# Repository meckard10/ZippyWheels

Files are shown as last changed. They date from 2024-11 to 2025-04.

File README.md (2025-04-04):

# ZippyWheels
Clemson Senior Design II Project

Melody Eckard, Xander Hagler, Nitya Harikumar, Karlee Kesler, Covington Loftus

## Overview

Remote-controlled roller skates project.

## Folders

1. /Pi PICOW C Code
	- contains C/C++ code for a Raspberry Pi Pico W

2. /Remote Design
	- contains PCB design files and 3D design for remote body
	- Autodesk EAGLE CAD, KiCAD, and SOLIDWORKS were used for these files

3. /Skate Design
	- contains 3D design files for skate body
	- Autodesk Inventor was used for these files

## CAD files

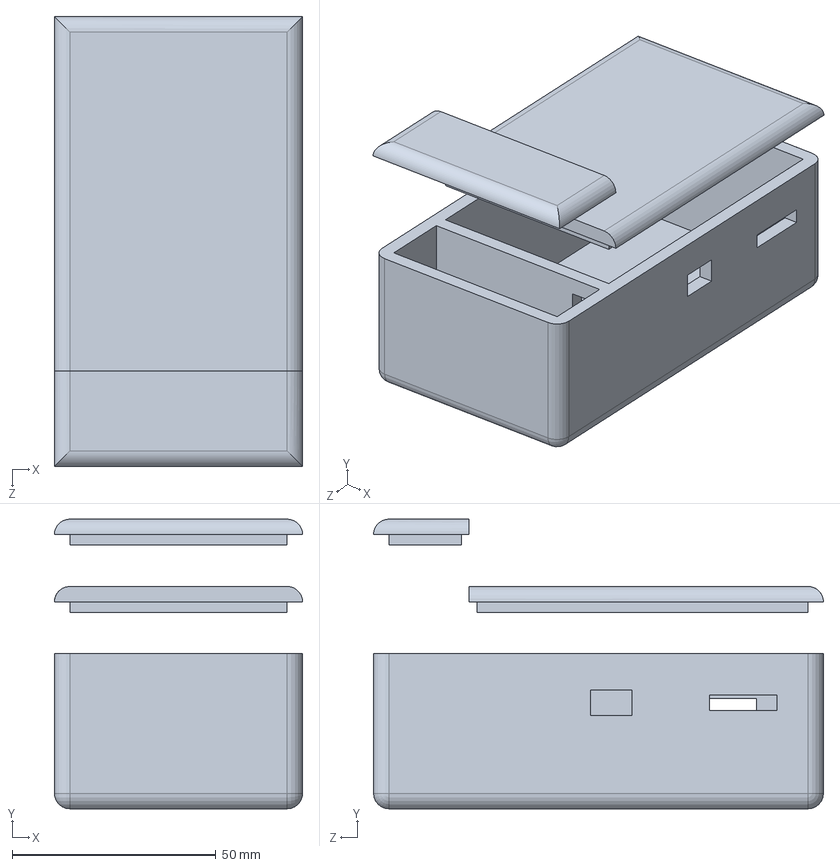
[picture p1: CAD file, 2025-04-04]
Remote_Design/remote.SLDPRT
61.0 x 71.1 x 110.5 mm

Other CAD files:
Remote_Design/remote.STL
Skate_Design/SkateBodyV2.ipt
Skate_Design/SkateLidV1.ipt

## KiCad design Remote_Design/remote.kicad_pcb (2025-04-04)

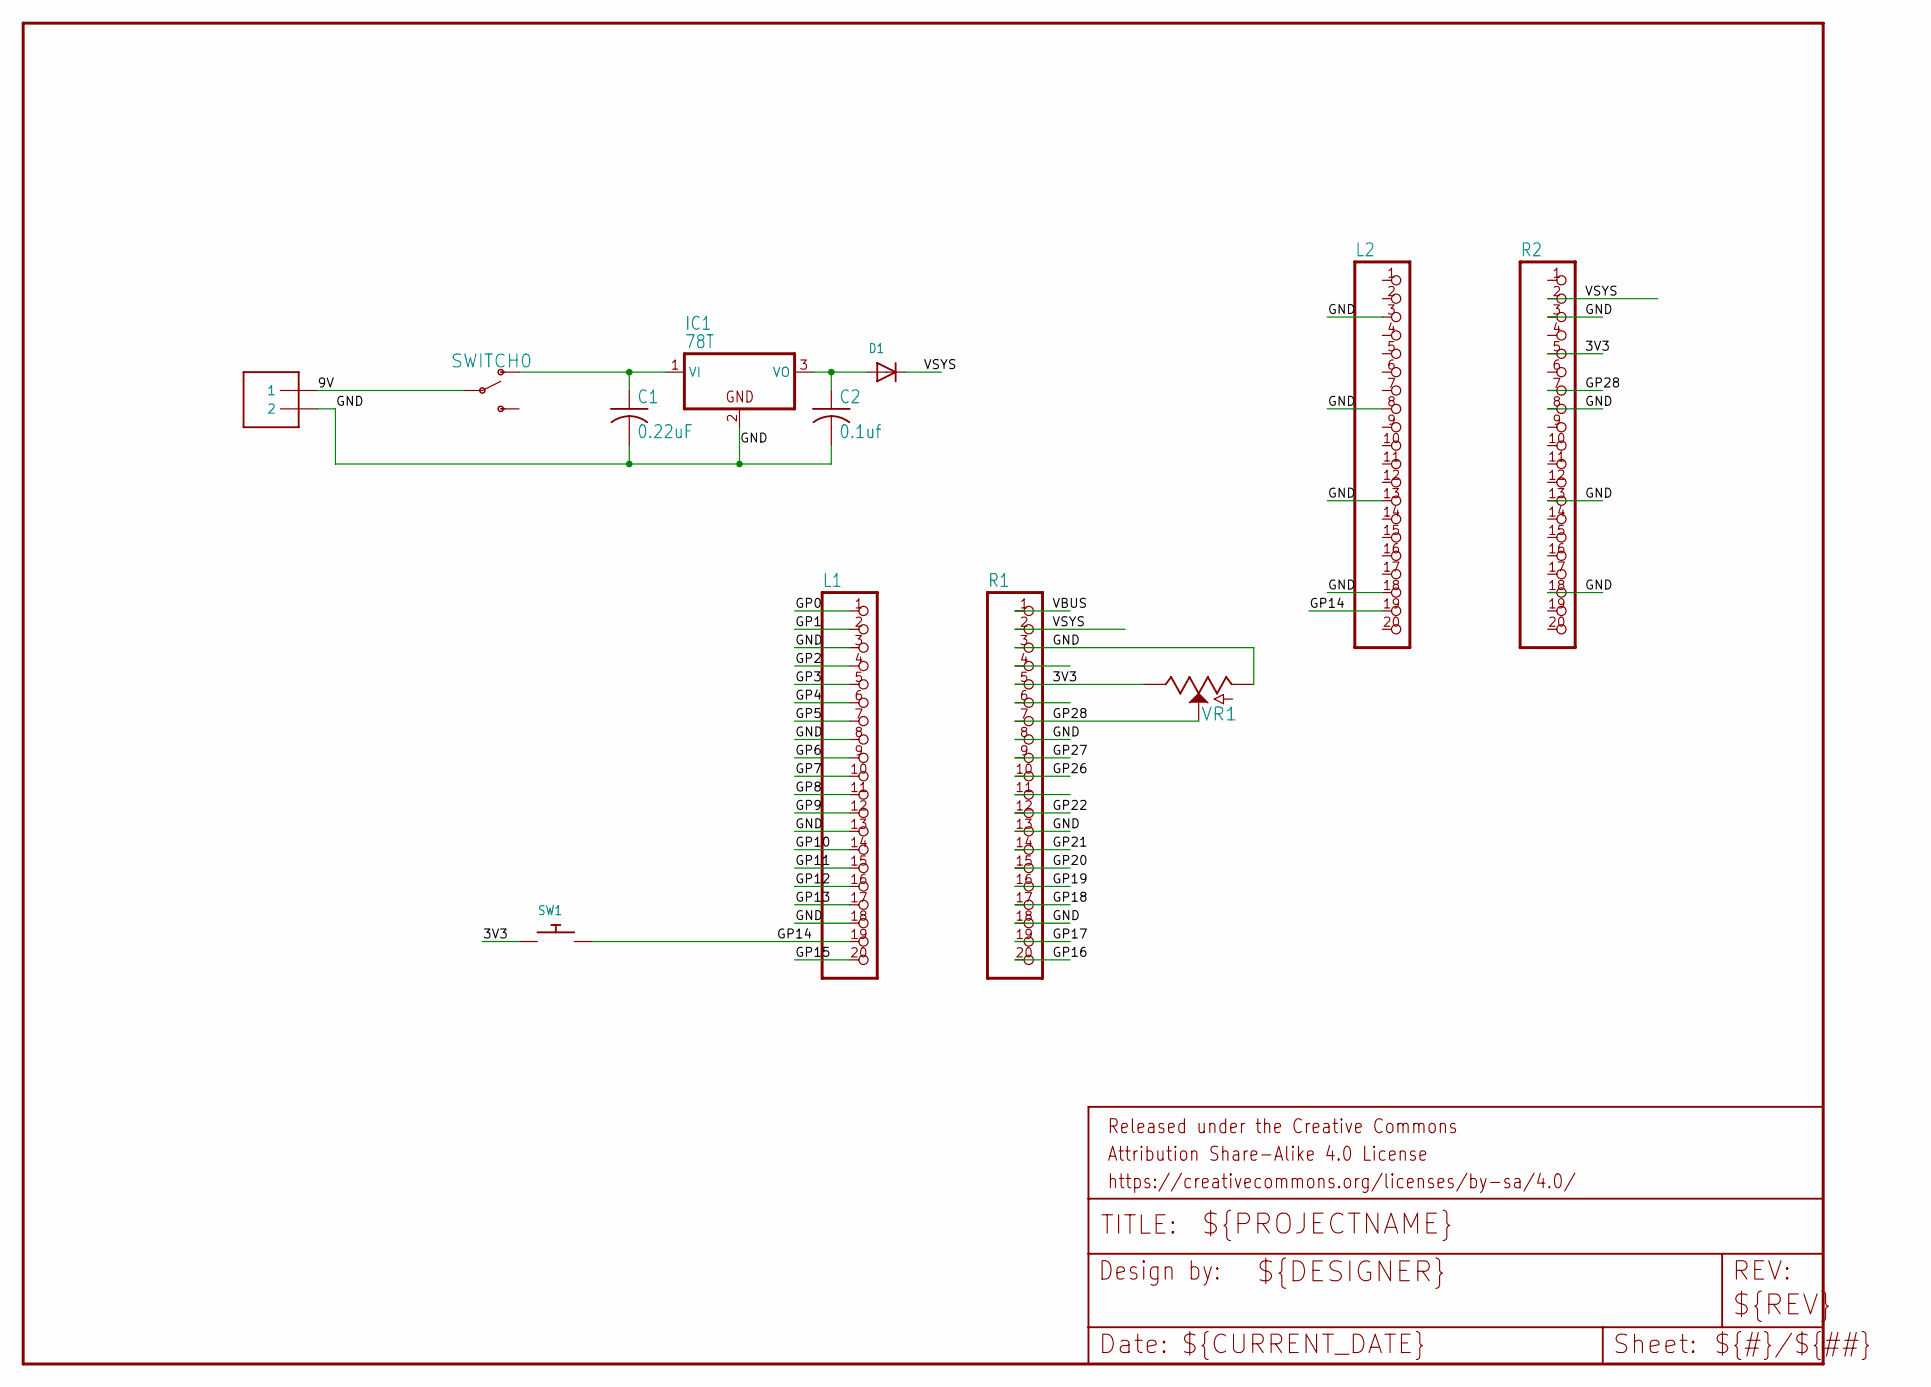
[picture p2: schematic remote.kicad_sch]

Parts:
C1: 0.22uF; C050-025X075
C2: 0.1uf; C050-025X075
D1: DIODEDO-1N4148; DO-1N4148
FRAME1: FRAME-LETTER; CREATIVE_COMMONS
IC1: 78T; TO220H
L1, L2: PINHD-1X20; 1X20
R1, R2: PINHD-1X20; 1X20
SW1: SWITCH_PUSHBUTTONEVQ-PE; TACT_PANA-EVQ
SWITCH0: SWITCH-SPDT-PTH-11.6X4.0MM-LOCK; SWITCH_SPDT_PTH_11.6X4.0MM_LOCK
UNK9VBAT0: 1X2-3.5MM
VR1: 10k; POT-PTH-ALPS

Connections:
3V3: R1.5, R2.5, SW1.P$1, VR1.P$1 (E)
9V: SWITCH0.2, UNK9VBAT0.1
GND: C1.2, C2.2, IC1.2 (GND), L1.3, L1.8, L1.13, L1.18, L2.3, L2.8, L2.13, L2.18, R1.3, R1.8, R1.13, R1.18, R2.3, R2.8, R2.13, R2.18, UNK9VBAT0.2, VR1.P$3 (A)
GP0: L1.1
GP1: L1.2
GP2: L1.4
GP3: L1.5
GP4: L1.6
GP5: L1.7
GP6: L1.9
GP7: L1.10
GP8: L1.11
GP9: L1.12
GP10: L1.14
GP11: L1.15
GP12: L1.16
GP13: L1.17
GP14: L1.19, L2.19, SW1.P$2
GP15: L1.20
GP16: R1.20
GP17: R1.19
GP18: R1.17
GP19: R1.16
GP20: R1.15
GP21: R1.14
GP22: R1.12
GP26: R1.10
GP27: R1.9
GP28: R1.7, R2.7, VR1.P$2 (S)
unnamed: C2.1, D1.A, IC1.3 (VO)
unnamed: C1.1, IC1.1 (VI), SWITCH0.1 (O)
VBUS: R1.1
VSYS: D1.C, R1.2, R2.2

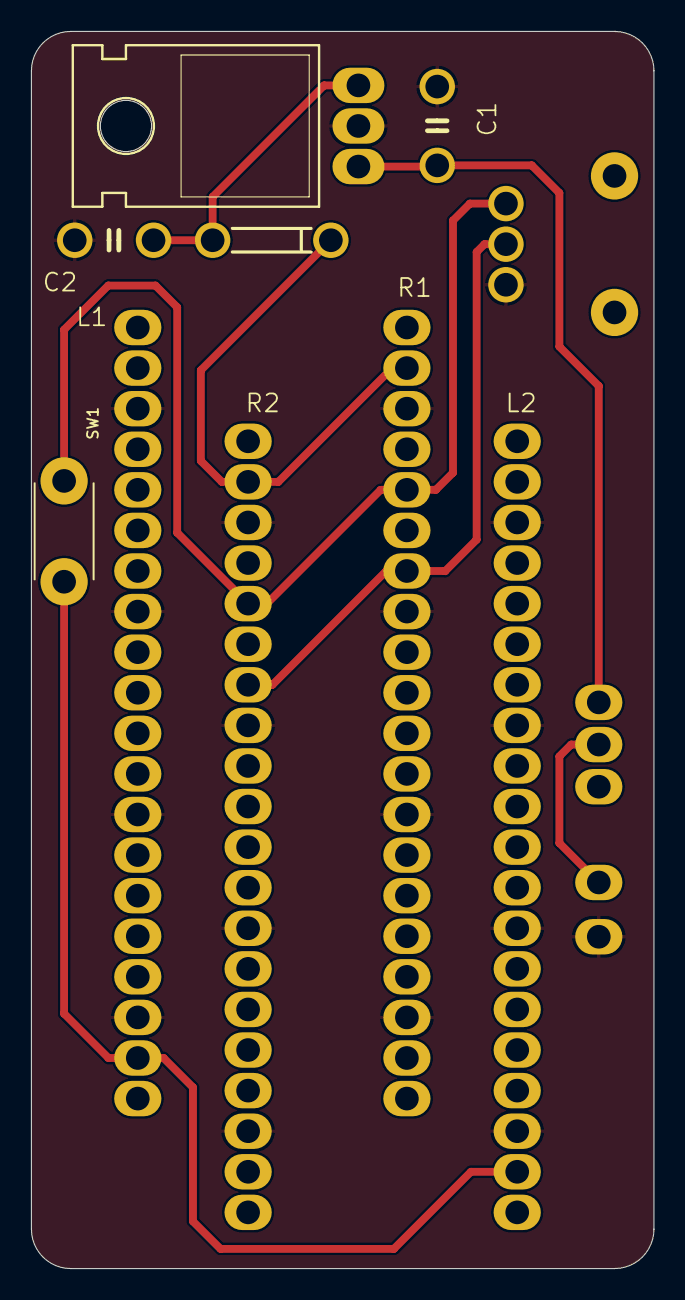
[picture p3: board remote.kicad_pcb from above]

Board: 2 copper layers, 40.1 x 79.8 mm, 13 parts (0 on the bottom side), 8 nets.

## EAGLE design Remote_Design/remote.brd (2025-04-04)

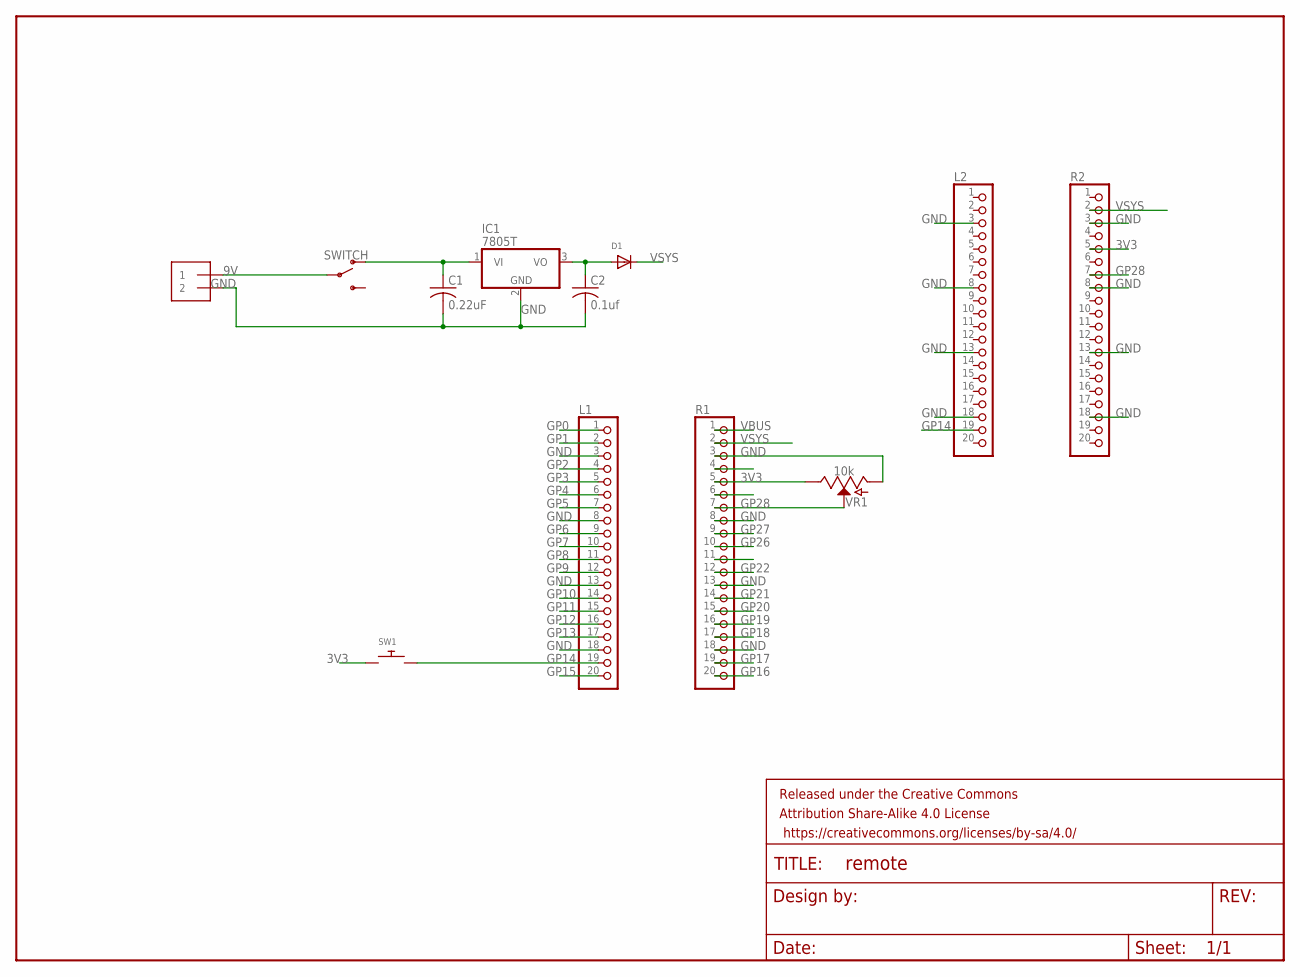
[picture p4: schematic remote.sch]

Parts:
9VBAT: 1X2-3.5MM
C1: 0.22uF; C050-025X075
C2: 0.1uf; C050-025X075
D1: DIODEDO-1N4148; DO-1N4148
FRAME1: FRAME-LETTER; CREATIVE_COMMONS
IC1: 7805T; TO220H
L1, L2: PINHD-1X20; 1X20
R1, R2: PINHD-1X20; 1X20
SW1: SWITCH_PUSHBUTTONEVQ-PE; TACT_PANA-EVQ
SWITCH: SWITCH-SPDT-PTH-11.6X4.0MM-LOCK; SWITCH_SPDT_PTH_11.6X4.0MM_LOCK
VR1: 10k; POT-PTH-ALPS

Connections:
3V3: R1.5, R2.5, SW1.P$1, VR1.P$1 (E)
9V: 9VBAT.1, SWITCH.2
GND: 9VBAT.2, C1.2, C2.2, IC1.2 (GND), L1.3, L1.8, L1.13, L1.18, L2.3, L2.8, L2.13, L2.18, R1.3, R1.8, R1.13, R1.18, R2.3, R2.8, R2.13, R2.18, VR1.P$3 (A)
GP0: L1.1
GP1: L1.2
GP2: L1.4
GP3: L1.5
GP4: L1.6
GP5: L1.7
GP6: L1.9
GP7: L1.10
GP8: L1.11
GP9: L1.12
GP10: L1.14
GP11: L1.15
GP12: L1.16
GP13: L1.17
GP14: L1.19, L2.19, SW1.P$2
GP15: L1.20
GP16: R1.20
GP17: R1.19
GP18: R1.17
GP19: R1.16
GP20: R1.15
GP21: R1.14
GP22: R1.12
GP26: R1.10
GP27: R1.9
GP28: R1.7, R2.7, VR1.P$2 (S)
unnamed: C2.1, D1.A, IC1.3 (VO)
unnamed: C1.1, IC1.1 (VI), SWITCH.1 (O)
VBUS: R1.1
VSYS: D1.C, R1.2, R2.2

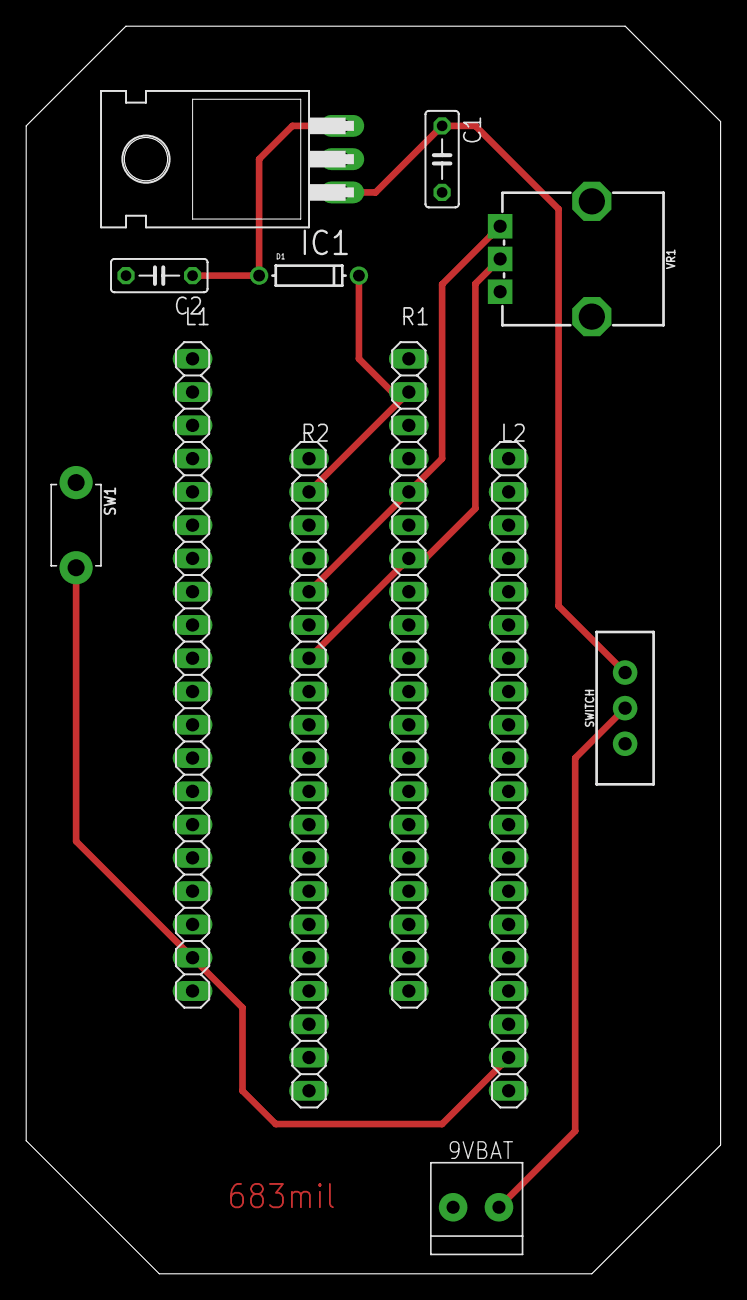
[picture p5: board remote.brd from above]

Board: 2 copper layers, 53.0 x 95.2 mm, 13 parts (0 on the bottom side), 8 nets.

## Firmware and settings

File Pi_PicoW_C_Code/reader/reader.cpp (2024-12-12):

////////////////////////////////////////////////////////////////////////////////
// Raspberry Pi Pico-W Bluetooth Reader Demo
// written by Travis Llado
// last edited 2023-11-08
////////////////////////////////////////////////////////////////////////////////

#include "hardware/pwm.h"
#include "pico/stdlib.h"
#include "stdio.h"

#include "bt_setup.h"

////////////////////////////////////////////////////////////////////////////////

#define PIN_PWM 21U
#define HALL_PAD 15
#define SCALING_FACTOR 65535/1295

uint16_t _received_duty_;
uint16_t _modified_duty_;
int pulseCount = 0;
int rpm = 0;

////////////////////////////////////////////////////////////////////////////////

void gpioIrqCallback(uint gpio, uint32_t event_mask){
	if ((event_mask & GPIO_IRQ_EDGE_RISE)> 0){
		pulseCount++; // Count the rising edges (voltage from hall sensor)
	}
}

void initialize_hall_sensor() {
   gpio_init(HALL_PAD);
   gpio_set_dir(HALL_PAD, GPIO_IN);
   gpio_pull_up(HALL_PAD);
   gpio_set_irq_enabled_with_callback(HALL_PAD, GPIO_IRQ_EDGE_RISE, true, gpioIrqCallback);
}

////////////////////////////////////////////////////////////////////////////////

void set_duty(void) {
  rpm = pulseCount*60/32; //32 pulses/revolutions * 60 seconds/min
  _modified_duty_ = _received_duty_;
  if (SCALING_FACTOR*(rpm-100) < _modified_duty_ ){
    _modified_duty_ += 10  ;
  }
  else if (SCALING_FACTOR*(rpm+100) > _modified_duty_ ){
    _modified_duty_ -= 10  ;
  }
  
  pwm_set_gpio_level(PIN_PWM, _modified_duty_);
}

////////////////////////////////////////////////////////////////////////////////

void init_pwm() {
  gpio_set_function(PIN_PWM, GPIO_FUNC_PWM);
  uint slice_num = pwm_gpio_to_slice_num(PIN_PWM);
  pwm_config config = pwm_get_default_config();
  pwm_config_set_clkdiv(&config, 40.0); //frequency
  pwm_init(slice_num, &config, true);
  pwm_set_gpio_level(PIN_PWM, 0U);
}

////////////////////////////////////////////////////////////////////////////////

int main() {
    stdio_init_all();

    init_pwm();
    initialize_hall_sensor();
    bt_init(&set_duty, &_received_duty_);
    bt_start();
    
    while(true) {  
       // Do nothing, all further activity handled by bt handlers
       sleep_ms(1000);

       //printf("RPM: %d\n", rpm); 
	rpm=0;    
       pulseCount = 0;
       
    }
    return 0;
}

////////////////////////////////////////////////////////////////////////////////
// End of file
////////////////////////////////////////////////////////////////////////////////

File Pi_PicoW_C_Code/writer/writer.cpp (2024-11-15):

////////////////////////////////////////////////////////////////////////////////
// Raspberry Pi Pico-W Bluetooth Writer Demo
// written by Travis Llado
// last edited 2023-11-07
////////////////////////////////////////////////////////////////////////////////


#include "hardware/adc.h"
#include "pico/stdlib.h"
#include "bt_setup.h"


////////////////////////////////////////////////////////////////////////////////


#define PIN_26_GPIO_CHANNEL 26U
#define PIN_26_ADC_CHANNEL  0U
#define BUTTON_PIN 14


uint16_t _adc_reading_;


////////////////////////////////////////////////////////////////////////////////


void read_adc(void) {
   adc_select_input(PIN_26_GPIO_CHANNEL);
   if (gpio_get(BUTTON_PIN)) {_adc_reading_ = 16*adc_read();}
   else {_adc_reading_ = _adc_reading_/1.10;} // when trigger is not pushed
}


////////////////////////////////////////////////////////////////////////////////


void initialize_adc() {
   adc_init();
   adc_gpio_init(PIN_26_GPIO_CHANNEL);
   adc_select_input(PIN_26_ADC_CHANNEL);
   adc_set_temp_sensor_enabled(true);
}


void initialize_button(){
   gpio_init(BUTTON_PIN);
   gpio_set_dir(BUTTON_PIN,GPIO_IN);
}


////////////////////////////////////////////////////////////////////////////////


int main() {
   stdio_init_all();
   initialize_adc();
   initialize_button();
   bt_init(&read_adc, &_adc_reading_);
   bt_start();
  
   while(true) {  
       // Do nothing, all further activity handled by bt handlers
       sleep_ms(1000);
   }
  
   return 0;
}


////////////////////////////////////////////////////////////////////////////////
// End of file
////////////////////////////////////////////////////////////////////////////////
////////////////////////////////////////////////////////////////////////////////

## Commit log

2024-10-22 Modified PWM signal and made som setting changes to bluetooth
2024-10-30 Update writer.cpp, add button
2024-11-15 Update reader.cpp, get hall sensor readings
2024-12-12 Update reader.cpp, hall sensor feedback
2025-04-04 added physical designs
    [SkateBodyV2.ipt, SkateLidV1.ipt, remote.SLDPRT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]

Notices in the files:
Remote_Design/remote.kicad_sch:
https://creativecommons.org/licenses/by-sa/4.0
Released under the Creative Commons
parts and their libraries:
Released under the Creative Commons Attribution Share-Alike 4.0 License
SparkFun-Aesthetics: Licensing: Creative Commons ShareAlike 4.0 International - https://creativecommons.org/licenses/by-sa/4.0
